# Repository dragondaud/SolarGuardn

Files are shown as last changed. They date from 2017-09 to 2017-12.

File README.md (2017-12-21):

# SolarGuardn
## v0.8.00 PRE-RELEASE 21-Dec-2017
### by David Denney <dragondaud@gmail.com>

Master repository: https://github.com/dragondaud/SolarGuardn

### Features
- ESP8266/Arduino platform
- Over-the-Air (OTA) updates from Arduino IDE
- BME280 to read Temperature, Humidity, Pressure
- Soil moisture reading
- MQTT data logging
- WiFi client
- WiFi web server
- Web server status page
- Telnet server for remote debugging/monitoring
- Pump control with SONOFF/Espurna
- SPIFFS config file

This code is offered "as is" with no warranty, expressed or implied, for any purpose,
and is released to the public domain, while all libraries retain their respective licenses.

See config.h for configurable settings and all includes.

Designed to run on an ESP-12E NodeMCU board with additional hardware,
this sketch will monitor soil conditions, ambient temperature, humidity
and atmospheric pressure, then report changes using MQTT, to AdafruitIO.

A built-in WWW server provides direct access to current data, /reset request will reboot ESP.

Telnet server allows remote monitoring and debugging when serial is not practical.

Press FLASH button on NodeMCU to enter moisture sensor calibration mode, adjust input pot, monitor serial

Press FLASH button twice rapidly to store current running config to SPIFFS

**Board: NodeMCU 1.0, Freq: 80MHz, Flash: 4M (1M SPIFFS), Speed: 115200, Port: serial or OTA IP**

Some code is based on examples from the ESP8266, ArduinoOTA and other libraries.

Sketch requires Arduino ESP8266 board library v2.4.0 from https://github.com/esp8266/Arduino#using-git-version

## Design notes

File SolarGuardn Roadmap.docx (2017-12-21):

# SolarGuardn Roadmap

## Config

WIFI

MQTT

BETWEEN

Fahrenheit

Sensor pins

## Setup

Serial begin

Read config

Set default hostname if null

WiFi begin

MDNS begin

Debug telnet begin

Get location

Config ntp

OTA begin

MQTT connect

GPIO pin modes

Sensor initialize

WWWserver begin

Uptime initialized

Output banner/crash info

## Loop

Restart ESP on null IP

OTA, MQTT, Debug, WWW … handle

Recheck time zone after 2am

Restart loop unless read interval reached

Read sensors

Construct JSON array with sensor data

Publish JSON to MQTT

Blink built-in LED

## Functions

UrlEncode

getIPlocation

getLocation

getTimeZone

setNTP

uptime

mqttConnect

mqttPublish

espStats

ttime

handleWWW

## Includes

ESP8266WiFi.h https://github.com/esp8266/Arduino

ArduinoJson.h https://github.com/bblanchon/ArduinoJson

BME280I2C.h https://github.com/finitespace/BME280

EspSaveCrash.h https://github.com/krzychb/EspSaveCrash

PubSubClient.h https://github.com/knolleary/pubsubclient

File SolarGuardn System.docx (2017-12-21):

# SolarGuardn System

## AirGuard

- ESP w/ Temperature, Humidity, TVOC / eCO2

## SoilGuard

- ESP w/ Temperature, Humidity, Soil Moisture

## TankGuard

- ESP w/ Temperature, Humidity, Ultrasonic Water Level

## LightGuard

- ESP w/ Temperature, Humidity, Full Spectrum Light Sensor

## GuardnPower

- SonOff w/ Power usage, pump/light/solenoid control

## GuardnHub

- Raspberry Pi W Zero, MQTT broker, nosql, automation

## Summary

The SolarGuardn System is made up of a variety of modules that monitor various aspects of the garden environment. Each guard module communicates with the GuardnHub for its configuration and to report data. The GuardnHub runs on a Raspberry Pi with Raspbian Linux. The hub provides a local front-end for module control, configuration, monitoring and event control, as well as uploading the data to the cloud. Without a local hub, all reporting, control and configuration activities rely on having a stable Internet connection.

## Hardware

Each Guard module is based on an ESP module of various types, contains an 18650 2500mAh lipo battery, and is powered either by a Solar cell or a USB charger. The ESP8266 supports WiFi, has one analog input, and several GPIOs available. The ESP32 supports WiFi and Bluetooth, has four analog inputs, and several GPIOs available. The SonOff-POW is an ESP8266 based power relay, with power monitoring built-in, though requires soldering a header inside to program.

SoilGuard uses a capacitive soil moisture sensor, which must be calibrated for the type of growing media and nutrients being used. It is very sensitive to depth of insertion and only works reliably when inserted into undisturbed soil to the correct depth, and not withdrawn or jostled. Improving the usability and reliability of this sensor has been a major focus.

## Parts

(example parts, for prototypes, available more cheaply on ebay)

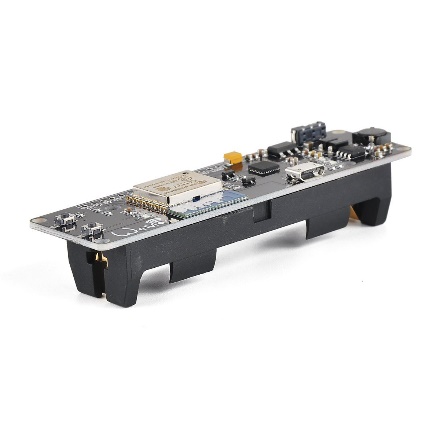
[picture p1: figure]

ESP8266 NodeMCU 1.0 with 18650 battery holder and charging circuit | http://a.co/518tkHj

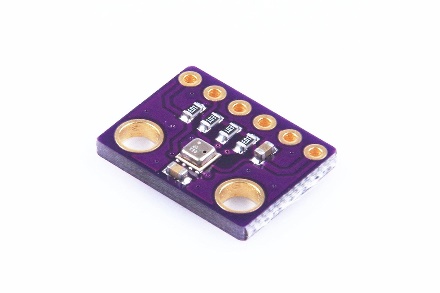
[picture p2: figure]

BME280 weather sensor | http://a.co/6fis93Z

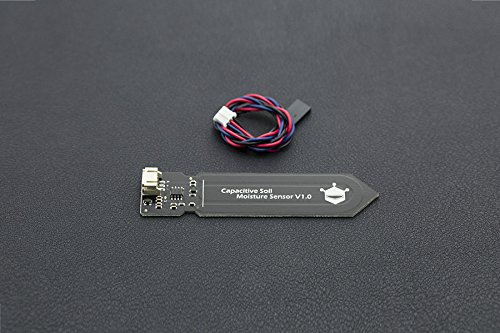
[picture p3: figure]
DFRobot Capacitive Soil Moisture Sensor- Corrosion Resistant

DFRobot Capacitive Soil Moisture sensor | http://a.co/3iVQXh5

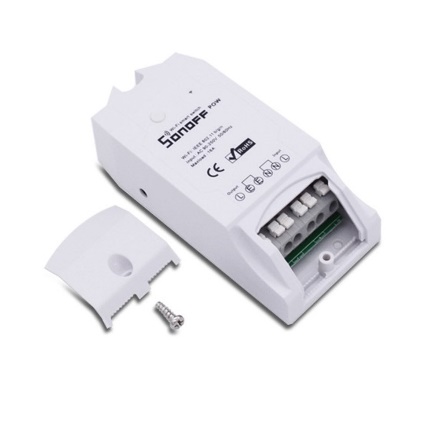
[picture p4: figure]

SonOff Pow | http://a.co/b1oLWcm

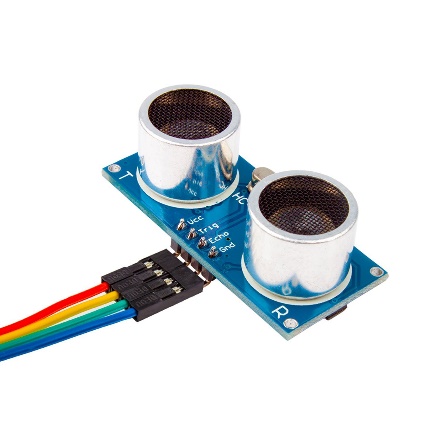
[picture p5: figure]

HC-SR04 Ultrasonic sensor | http://a.co/6q1ENUZ

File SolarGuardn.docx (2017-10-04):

# SolarGuardn v0.7.05 PRE-RELEASE

# Parts

(Only one of each part is needed, but some things are cheaper in quantity if you don’t have them laying around already. The parts specified above are just examples, use what you have laying around or can find locally, as desired)

Description | Source | Price
NodeMCU devkit V1.0 ESP-12E | http://a.co/10eGSEd | $8.69
Solderable Protoboard | http://a.co/g65cxVk (qty 3) | $12.52
Yard light to hack | http://a.co/i6eFgRK | $9.99
DC to DC Voltage Regulator | http://a.co/eJytx5X (qty 5) | $7.99
10K ohm trim pot | http://a.co/iqWQHtd (qty 10) | $7.99
BME280 I2C Weather Sensor | http://a.co/6fis93Z | $12.72
100ohm resistor | http://a.co/1EHDSJW (qty100) | $5.16
NPN transistor | http://a.co/6SemMNQ (qty 100) | $5.90
Electrolytic Capacitor | http://a.co/3eo9hUW | $5.86
Sonoff POW | https://www.itead.cc/sonoff-pow.html | $10.50

I suggest building your circuit on a solderless breadboard first, then transfer to soldered protoboard once you are satisfied with its operation. I highly recommend soldering female header strips to your PCB for the NodeMCU, the BME module and even the transistor, so they’re easily replaced or repurposed.

# Features

- ESP8266/Arduino platform
- Over-the-Air (OTA) updates from Arduino IDE
- BME280 to read Temperature, Humidity, Pressure
- Soil moisture reading
- AdafruitIO/MQTT data logging
- WiFi client, to control other devices
- WiFi web server, for status page and remote reset
- Pump control by custom URL (works with ESPurna (https://bitbucket.org/xoseperez/espurna))
- SPIFFS config file, eventually configured thru web page

# pin definitions

GPIO | Pin label | Description
ADC | A0 | MOIST (analog)
4 | D2 | MPOW
0 | D3 | BUTTON (flash)
14 | D5 | I2C-CLK
12 | D6 | I2C-DAT

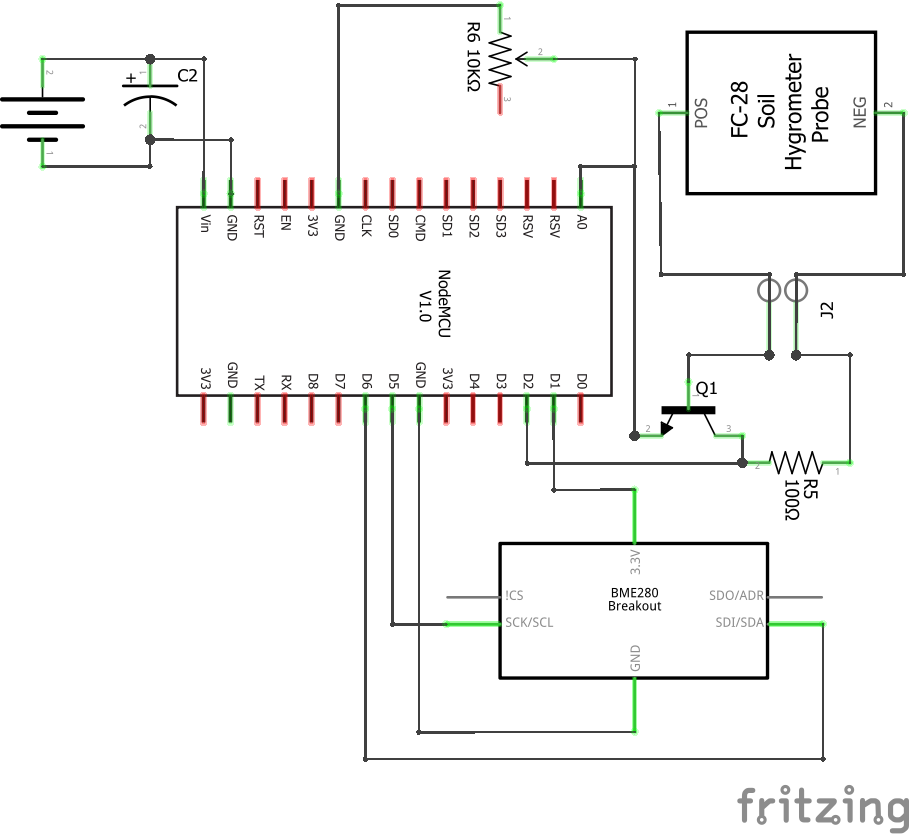
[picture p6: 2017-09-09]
SolarGuardn_schem.png

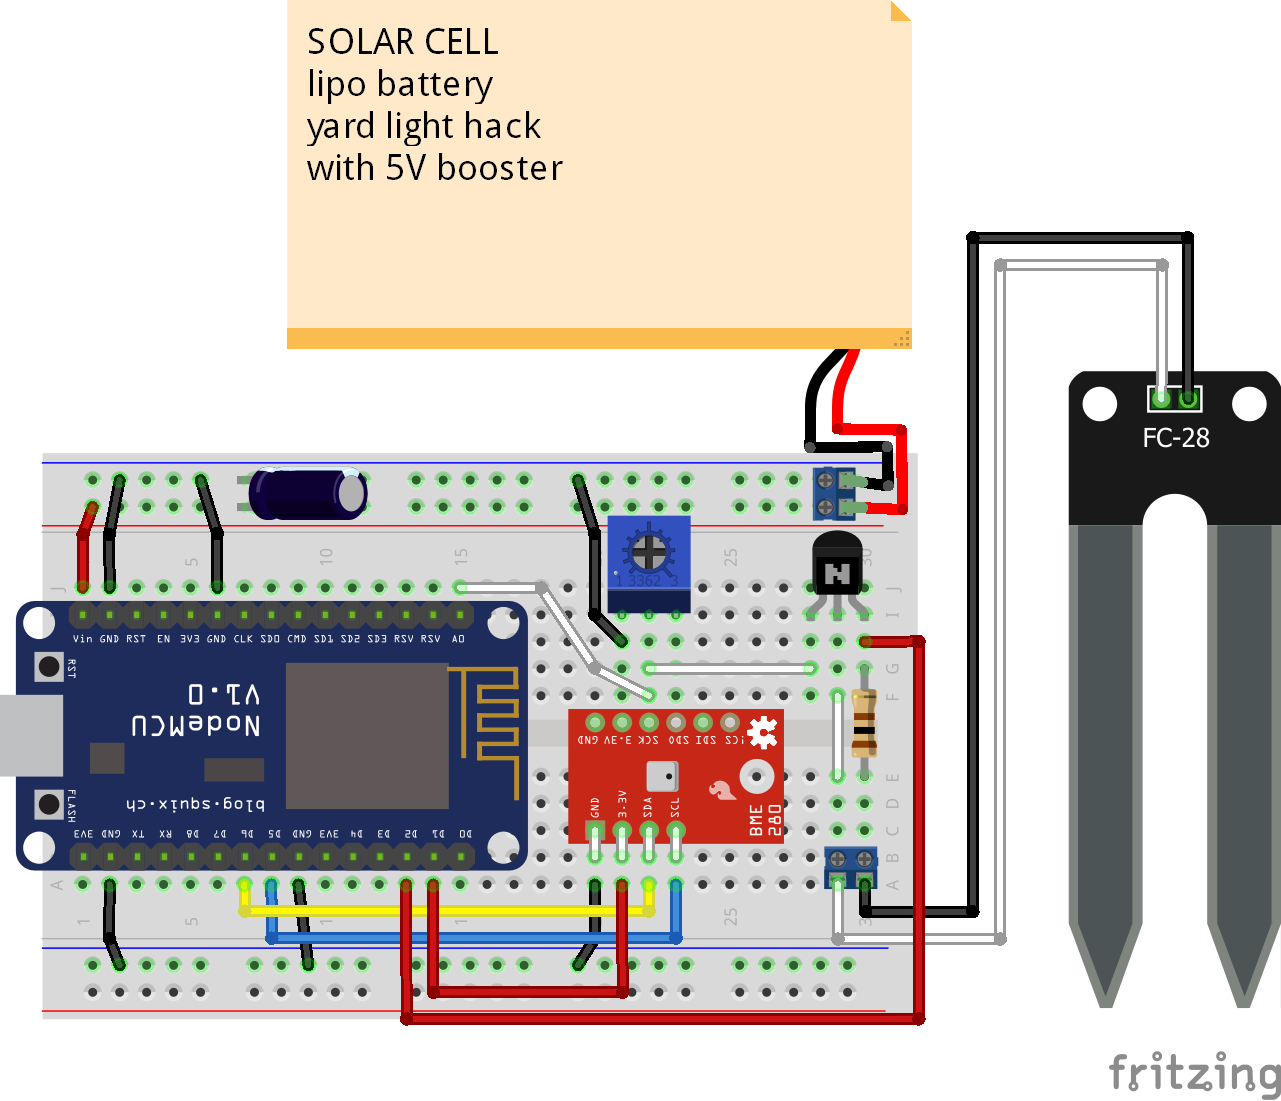
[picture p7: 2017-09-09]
SolarGuardn_bb.png

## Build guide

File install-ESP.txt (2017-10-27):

INSTALL
-------

Install Arduino IDE from http://www.arduino.cc/en/main/software
Install Python 2.7-latest from https://www.python.org/downloads/windows/
Install Github from https://central.github.com/deployments/desktop/desktop/latest/win32

Launch 'Git Bash'

cd ~/Documents/Arduino/
mkdir hardware
cd hardware
mkdir esp8266com
cd esp8266com
git clone https://github.com/esp8266/Arduino.git esp8266
cd esp8266
git fetch origin pull/3362/head:lwip2v2
git merge lwip2v2
cd tools
python get.py

UPDATE
------

Launch 'Git Bash'

cd ~/Documents/Arduino/hardware/esp8266com/esp8266
git fetch origin pull/3362/head:lwip2v2
git merge lwip2v2

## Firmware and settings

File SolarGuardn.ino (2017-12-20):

/*
  SolarGuardn v0.8.00 PRE-RELEASE 26-Oct-2017
  by David Denney

  Monitors garden conditions, cycles irrigation control as needed, reports data using MQTT.

  This code is offered "as is" with no warranty, expressed or implied, for any purpose,
  and is released to the public domain, while all libraries retain their respective licenses.

  Master repository: https://github.com/dragondaud/SolarGuardn

  See config.h for configurable settings and includes.

  Designed to run on an ESP-12E NodeMCU board with additional hardware,
  this sketch will monitor soil conditions, ambient temperature, humidity
  and atmospheric pressure, then report changes using MQTT.

  Built-in WWW server:
    / : display temperature, humidity, pressure, soil moisture
    /reset : reboot module
    /calibrate : start calibration
    /crash : display any saved crash report

  Telnet server allows remote monitoring and debugging when serial is not practical.

  Board: NodeMCU 1.0, Freq: 80MHz, Flash: 4M (1M SPIFFS), Speed: 115200, Port: serial or OTA IP

  Some code is based on examples from the ESP8266, ArduinoOTA and other libraries.

  Sketch requires ESP8266 library v2.4.0-rc1, docs at: https://arduino-esp8266.readthedocs.io/en/2.4.0-rc1/
  You can use the release candidate by adding  this to File->Preferences->Additional Board Manager URLs:
    https://github.com/esp8266/Arduino/releases/download/2.4.0-rc1/package_esp8266com_index.json
*/

#include "config.h"

void setup() {
  Serial.begin(115200);               // Initialize Serial at 115200bps, to match bootloader
  //Serial.setDebugOutput(true);      // uncomment for extra debugging
  while (!Serial);                    // wait for Serial to become available
  delay(100);
  debugOutLN(F("\033[H\033[2JSolarGuardn starting..."));     // CLS and startup banner

  readConfig();                       // mount SPIFFS, config file not implemented yet

  if (HOST == "") {                   // default hostname "SG-000000" where 0000 is last 6 digts of MACaddr
    String t = WiFi.macAddress();
    HOST = "SG-" + t.substring(9, 11) + t.substring(12, 14) + t.substring(15, 17);
  }

  /* WiFi connect */
  WiFi.hostname(HOST);
#ifdef DEBUG
  debugOut("Connecting to ");
  debugOut(WIFI_SSID);
#endif
  WiFi.begin(WIFI_SSID.c_str(), WIFI_PASS.c_str());
  while (WiFi.status() != WL_CONNECTED) {
#ifdef DEBUG
    debugOut(FPSTR(DOT));
#endif
    delay(500);
  }
#ifdef DEBUG
  debugOutLN();
#endif

  /* configTime sntp */
  configTime((TZ * 3600), 0, "pool.ntp.org", "time.nist.gov");
#ifdef DEBUG
  debugOut(F("Synchronize clock with sntp..."));
#endif
  while (!time(nullptr)) {
    delay(1000);                        // wait for ntp time sync
#ifdef DEBUG
    debugOut(FPSTR(DOT));
#endif
  }
#ifdef DEBUG
  debugOutLN();
#endif

#ifdef OTA
  ArduinoOTA.setHostname(HOST.c_str());
  ArduinoOTA.setPort(OTA_PORT);
  if (OTA_PASS) ArduinoOTA.setPassword(OTA_PASS.c_str());
  ArduinoOTA.onStart([]() {
    SPIFFS.end();
    Serial.println(F("\r\nOTA Start"));
  } );
  ArduinoOTA.onEnd([]() {
    Serial.println(F("\r\nOTA End"));
    SPIFFS.begin();
  } );
  ArduinoOTA.onProgress([](unsigned int progress, unsigned int total) {
    Serial.print("OTA Progress: " + String((progress / (total / 100))) + " \r");
  });
  ArduinoOTA.onError([](ota_error_t error) {
    debugOut("Error[" + String(error) + "]: ");
    if (error == OTA_AUTH_ERROR) Serial.println(F("Auth Failed"));
    else if (error == OTA_BEGIN_ERROR) Serial.println(F("Begin Failed"));
    else if (error == OTA_CONNECT_ERROR) Serial.println(F("Connect Failed"));
    else if (error == OTA_RECEIVE_ERROR) Serial.println(F("Receive Failed"));
    else if (error == OTA_END_ERROR) Serial.println(F("End Failed"));
    else Serial.println(F("unknown error"));
    ESP.restart();
  });
  ArduinoOTA.begin();
#ifdef DEBUG
  debugOutLN(F("OTA handler started"));
#endif
#endif // OTA

#ifdef WWW
  wwwServer.begin(); /* start web server */
#ifdef DEBUG
  debugOutLN(F("WWW server started"));
#endif
#endif // WWW

  pinMode(LED_BUILTIN, OUTPUT);   // enable onboard LED output
  pinMode(MGND, OUTPUT);          // moisture sensor ground
  digitalWrite(MGND, LOW);        // moisture sensor ground
  pinMode(MPOW, OUTPUT);          // moisture sensor power
  digitalWrite(MPOW, LOW);        // moisture sensor power
  pinMode(BGND, OUTPUT);          // weather ground output
  digitalWrite(BGND, LOW);        // weather ground low
  pinMode(BPOW, OUTPUT);          // weather power output
  digitalWrite(BPOW, HIGH);       // weather power always on, builtin power saving

  Wire.begin(BDAT, BCLK);         // start I2C for weather sensor
  Wire.setClock(100000);
#ifdef BME
  isBME = bme.begin(BMEid);
  bme.setSampling(Adafruit_BME280::MODE_FORCED,
                  Adafruit_BME280::SAMPLING_X4,  // temperature
                  Adafruit_BME280::SAMPLING_X1,  // pressure
                  Adafruit_BME280::SAMPLING_X4,  // humidity
                  Adafruit_BME280::FILTER_OFF   );
  if (!isBME) debugOutLN(F("Could not find a valid BME280 sensor"));
#else
  hdc.begin(0x40);
  isBME = true;
#endif

#ifdef TELNET
#ifdef DEBUG
  debugOutLN(F("telnet server started"));
#endif
  telnetServer.begin();
  //telnetServer.setNoDelay(true); // drops chars if set true
#endif // TELNET

#ifdef MQTT
  MQTTclient.setServer(MQTT_SERV.c_str(), MQTT_PORT);
  MQTTconnect();
#endif

  controlWater(false);                            // start with water control off

  long tStart = time(nullptr);    // measure delay() accuracy in seconds and reset loop DELAY
  delay(DELAY);
  long tEnd = time(nullptr);
  DELAY = (DELAY / ((tEnd - tStart) * 1000)) * DELAY;

#ifdef DEBUG
  SaveCrash.print();
  espStats();
  debugOut(F("Ready, at "));
  debugOut(ttime() + " (");
  debugOut(DELAY);
  debugOutLN(")");
#endif
} // setup()

#ifdef MQTT
bool publish (String t, String m) {
  String topic = MQTT_TOPIC + "/" + t;
  if (!MQTTclient.connected()) MQTTconnect();
  return MQTTclient.publish(topic.c_str(), m.c_str());
} // publish()

bool MQTTconnect () {
  bool r = MQTTclient.connect(HOST.c_str(), MQTT_USER.c_str(), MQTT_PASS.c_str());
  if (r) {
#ifdef DEBUG
    debugOutLN("Connected to MQTT on " + MQTT_SERV + ":" + String(MQTT_PORT));
    publish("debug", WiFi.localIP().toString() + " " + ESP.getResetReason());
#endif
  } else {
#ifdef DEBUG
    debugOutLN("Could not connect to " + MQTT_SERV);
#endif
  }
  return r;
}
#endif

template <typename T> void debugOut(const T x) {
  Serial.print(x);
#ifdef TELNET
  if (telnetClient && telnetClient.connected()) {
    telnetClient.print(x);
  }
#endif
  yield();
} // debugOut()

void debugOutLN() {
  debugOut(FPSTR(EOL));
}

template <typename T> void debugOutLN(const T x) {
  debugOut(x);
  debugOut(FPSTR(EOL));
} // debugOutLN()

#ifdef TELNET
void handleTelnet(void) {
  if (telnetServer.hasClient()) {
    if (!telnetClient || !telnetClient.connected()) {
      if (telnetClient) {
        telnetClient.stop();
      }
      telnetClient = telnetServer.available();
      telnetClient.flush();
      yield();
#ifdef DEBUG
      debugOut(F("\r\ntelnet connected from "));
      debugOutLN(telnetClient.remoteIP());
#ifdef MQTT
      publish("debug", "telnet " + telnetClient.remoteIP().toString());
#endif
      SaveCrash.print(telnetClient);
      SaveCrash.clear();
      espStats();
#endif
    } else {
      telnetServer.available().stop();
    }
  }
} // handleTelnet()
#endif // TELNET

String upTime() {
  long t = millis() / 1000;
  long s = t % 60;
  long m = (t / 60) % 60;
  long h = (t / (60 * 60)) % 24;
  char ut[10];
  snprintf(ut, sizeof(ut), "%d:%02d:%02d", h, m, s);
  return String(ut);
} // upTime()

void espStats() {
  debugOut(F("SolarGuardn v"));
  debugOutLN(VERSION);
  debugOut(F("Last reset reason: "));
  debugOutLN(ESP.getResetReason());
  debugOut(F("WiFi Hostname: "));
  debugOutLN(WiFi.hostname());
  debugOut(F("WiFi IP addr: "));
  debugOutLN(WiFi.localIP());
  debugOut(F("WiFi MAC addr: "));
  debugOutLN(WiFi.macAddress());
  debugOut(F("WiFi Strength: "));
  debugOutLN(WiFi.RSSI());
  debugOut(F("ESP core version: "));
  debugOutLN(ESP.getCoreVersion());
  debugOut(F("ESP SDK version: "));
  debugOutLN(ESP.getSdkVersion());
  debugOut(F("ESP sketch size: "));
  debugOutLN(ESP.getSketchSize());
  debugOut(F("ESP Flash free: "));
  debugOutLN(ESP.getFreeSketchSpace());
  debugOut(F("ESP Flash Size: "));
  debugOutLN(ESP.getFlashChipRealSize());
  debugOut(F("ESP Flash ChipId: "));
  debugOutLN(ESP.getFlashChipId());
  debugOut(F("ESP free RAM: "));
  debugOutLN(ESP.getFreeHeap());
  debugOut(F("ESP uptime: "));
  debugOutLN(upTime());
  debugOutLN("Moisture range: " + String(WATER) + " > Soaked > " + String(WATER - interval) \
             + " > Wet > " + String(AIR + interval) + " > Dry > " + String(AIR));
} // espStats()

void controlWater(bool cmd) {         // control Sonoff module running ESPurna
#ifdef WATERCON
  HTTPClient http;
  if (cmd) {                          // true == turn on pump
    if ((wTime) && (((millis() - wTime) / 1000) < MINWAIT)) return; // wait before turning pump back on
    http.begin(onURL);
#ifdef DEBUG
    debugOut(F("Water ON"));
#endif
  } else {
    http.begin(offURL);
#ifdef DEBUG
    debugOut(F("Water off"));
#endif
  }
  int httpCode = http.GET();
  if (httpCode > 0) {
#ifdef DEBUG
    debugOutLN("; [HTTP] GET: " + String(httpCode));
#endif
    if (httpCode == HTTP_CODE_OK) {             // only change pump state if successful
      if ((water) || (cmd)) wTime = millis();   // track pump time
      water = cmd;
#ifdef MQTT
      if (cmd) publish("water", "ON");
      else publish("water", "OFF");
#endif
    }
  } else {
#ifdef MQTT
    publish("debug", http.errorToString(httpCode));
#endif
    debugOutLN(" [HTTP] GET failed: " + http.errorToString(httpCode));
  }
  http.end();
#endif
}

void calibrate() {
  debugOutLN(F("==Calibrate Start=="));
  for (int i = 1; i <= 25; i++) {
    yield();
    digitalWrite(MPOW, HIGH);
    delay(i * 10);
    debugOut(String(i * 10) + ":");
    int r = 1023 - analogRead(MOIST);
    digitalWrite(MPOW, LOW);
    debugOut(r);
    delay(i * 12);
    if ((i == 10) || (i == 19) || (i == 25)) debugOut(FPSTR(EOL));
    else debugOut(F(", "));
  }
  debugOutLN(F("==Calibrate End=="));
  startCalibrate = false;
} // calibrate()

int readMoisture(bool VERBOSE) {      // analog input smoothing
  int s = 0;
  for (int i = 0; i < nREAD; i++) {
    int r = 0, x = 0;
    do {
      digitalWrite(MPOW, HIGH);       // power to moisture sensor
      delay(STIME);
      r = 1023 - analogRead(MOIST);   // read analog value from moisture sensor (invert for capacitance sensor)
      digitalWrite(MPOW, LOW);        // turn off moisture sensor
      delay(STIME * 1.2);
      x++;
    } while (((r < AIR) || (r > WATER)) && x < nREAD);  // skip invalid values
    s += r;
    if (VERBOSE) {                    // during calibration, output all values
      debugOut(r);
      debugOut(FPSTR(COMMA));
    }
  }
  int r = round((float)s / (float)nREAD);
  if (VERBOSE) {
    debugOut(F("\b\b = "));
    debugOutLN(r);
  }
  return r;
} // readMoisture()

void readBME() {
  if (!isBME) return;
#ifdef BME
  bme.takeForcedMeasurement();
  temp = bme.readTemperature();                   // read Temp in C
#else
  temp = hdc.readTemperature();                   // read Temp in C
#endif
  if (FAHRENHEIT) temp = temp * 1.8F + 32.0F;     // convert to Fahrenheit
#ifdef BME
  humid = bme.readHumidity();                     // read Humidity
  pressure = round(bme.readPressure() * 0.02953); // read barometric pressure and convert to inHg
#else
  humid = hdc.readHumidity();                     // read Humidity
#endif
}                                                 /*-- add configure option for hPa or inHg --*/

void doMe() {                             // called every 5 seconds to handle background tasks
#ifdef TELNET
  handleTelnet();                         // handle telnet server
  yield();                                // process background tasks
#endif
#ifdef OTA
  ArduinoOTA.handle();                    // handle OTA update requests every 5 seconds
  yield();
#endif
#ifdef MQTT
  if (!MQTTclient.connected()) MQTTconnect();      // reconnect MQTT if needed
  MQTTclient.loop();                               // handle MQTT messages
  yield();
#endif
#ifdef WWW
  WiFiClient client = wwwServer.available(); // serve web requests
  if (client) handleWWW(client);
  yield();
#endif
  if (startCalibrate) calibrate();
  yield();
} // doMe()

void loop() {
  doMe();
  analogWrite(LED_BUILTIN, 1);  // turn on LED to half brightness while collecting sensor input
  readBME();
  soil = readMoisture(false);
#ifdef DEBUG
  debugOut(String(temp, 2));
  if (FAHRENHEIT) debugOut(F("°F, "));
  else debugOut(F("°C, "));
  debugOut(String(humid, 2));
  debugOut(F("% RH, "));
  debugOut(String(pressure / 100.0F, 2));
  debugOut(F(" inHg, "));
  debugOut(soil);
#endif
  if (soil > (AIR + interval)) {
#ifdef DEBUG
    if (soil > (WATER - interval)) debugOutLN(F(" soaked."));
    else debugOutLN(F(" wet."));
#endif
    if (water) {
#ifdef MQTT
      if (soil > (WATER - interval)) {
        publish("debug", "soaked off");
      } else publish("debug", "wet off");
#endif
      controlWater(false);
    }
  } else {
#ifdef DEBUG
    debugOutLN(F(" dry."));
#endif
    if (!water) controlWater(true);
  }
  if (soil != soil_l) {                   // if moisture level has changed then
#ifdef DEBUG
    debugOutLN("save moisture " + String(soil));
#endif
#ifdef MQTT
    publish("moist", String(soil));    // store soil moisture
#endif
    soil_l = soil;
  }
  int tt = round(temp);                   // round off temperature
  if (tt != temp_l && tt < 120) {         // if temp has changed and is valid then
#ifdef DEBUG
    debugOut("save temperature " + String(tt));
    if (FAHRENHEIT) debugOutLN(F("°F"));
    else debugOutLN(F("°C"));
#endif
#ifdef MQTT
    publish("temp", String(tt));       // store rounded temp
#endif
    temp_l = tt;
  }
  int hh = round(humid);                  // round off humidity
  if (hh != humid_l && hh <= 100) {       // if humidity has changed and is valid then
#ifdef DEBUG
    debugOutLN("save humidity " + String(hh) + "%RH");
#endif
#ifdef MQTT
    publish("humid", String(hh));      // store rounded humidity
#endif
    humid_l = hh;
  }
  if (pressure != pressure_l && pressure <= 3000) { // if pressure has changed and is valid then
    char p[10];
    dtostrf(pressure / 100.0F, 5, 2, p);  // convert to string with two decimal places
#ifdef DEBUG
    debugOut(F("save pressure "));
    debugOut(p);
    debugOutLN(F(" inHg"));
#endif
#ifdef MQTT
    publish("pressure", String(p));       // store inHg pressure
#endif
    pressure_l = pressure;
  }
  for (int i = 23; i < 1023; i++) {       // fade LED before sleep loop
    analogWrite(LED_BUILTIN, i);
    delay(1);
  }
  analogWrite(LED_BUILTIN, 0);            // disable analog output on LED
  digitalWrite(LED_BUILTIN, HIGH);        // turn off LED
  for (int x = 0; x < 12; x++) {          // sleep 1 minute between moisture readings to save power
    doMe();                               // while allowing background tasks to run every 5 seconds
    if ((water) && ((readMoisture(false) > AIR + interval) || (((millis() - wTime) / 1000) > MAXWATER))) {
#ifdef MQTT
      publish("debug", "time off");
#endif
      controlWater(false);
    }
#ifdef DEBUG
    debugOut(ttime() + " (" + ESP.getFreeHeap() + " free) \033[K\r");
#endif
    delay(DELAY);                          // delay() allows background tasks to run each invocation
  } // for x
} // loop()

String ttime() {
  time_t now = time(nullptr);
  String t = ctime(&now);
  t.trim();                               // formated time contains \n, bug?
  return t;
} // ttime()

#ifdef WWW
void handleWWW(WiFiClient client) {       // default request serves STATUS page
  if (!client.available()) return;
  char buf[1000];
  char p[10];
  String req = client.readStringUntil('\r');
  String tim = ttime(), upt = upTime();
  client.flush();
#ifdef DEBUG
#ifdef MQTT
  publish("debug", "WWW " + client.remoteIP().toString());
#endif
  debugOut(req);
  debugOut(F(" from "));
  debugOut(client.remoteIP());
#endif
  req.toUpperCase();
  if (req.startsWith("GET /FAV")) {             // send favicon.ico from data directory
    File f = SPIFFS.open("/favicon.ico", "r");
    if (!f) return;
#ifdef DEBUG
    debugOut(F(" send favicon.ico at "));
    debugOutLN(tim);
#endif
    client.println(FPSTR(HTTPOK));
    client.println(F("Content-Type: image/x-icon"));
    client.print(F("Content-Length: "));
    client.println(f.size());
    client.println();
    client.write(f);  // ESP8266 Arduino 2.4.0 library automatically buffers file by just passing handle
    client.flush();
    client.stop();
    f.close();
    return;
  }
  else if (req.startsWith("GET /ROBOT")) {      // robots.txt just in case
#ifdef DEBUG
    debugOut(F(" send robots.txt at "));
    debugOutLN(tim);
#endif
    client.println(FPSTR(HTTPOK));
    client.println(F("Content-Type: text/plain"));
    client.println();
    client.println(F("User-agent: *"));
    client.println(F("Disallow: /"));
    client.flush();
    client.stop();
    return;
  }
  else if (req.startsWith("GET /CAL")) {        // CALIBRATE will start moisture sensor calibration
#ifdef DEBUG
    debugOut(F(" start calibration at "));
    debugOutLN(tim);
#endif
    client.println(F("HTTP/1.1 204 No Content"));
    client.println();
    client.flush();
    client.stop();
    startCalibrate = true;
    return;
  }
  else if (req.startsWith("GET /RESET")) {        // RESET will restart ESP
    client.println(F("HTTP/1.1 204 No Content"));
    client.println();
    client.flush();
    client.stop();
    debugOut(F(" restart ESP at "));
    debugOutLN(tim);
    delay(500);                                   // delay to close connection before reset
    ESP.restart();
  }
  dtostrf(pressure / 100.0F, 5, 2, p);
  snprintf_P(buf, sizeof(buf), WWWSTAT, VERSION, tim.c_str(), upt.c_str(), temp_l, humid_l, p, soil);
  client.println(buf);
  if (req.startsWith("GET /CRASH")) {
    client.println("<pre>");
    SaveCrash.print(client);
    client.println("</pre>");
    SaveCrash.clear();
  }
  client.println("</body></html>");
  client.flush();
  client.stop();
#ifdef DEBUG
  debugOutLN(" send status (" + String(strlen(buf)) + " bytes) at " + tim);
#endif
} // handleWWW()
#endif // WWW

void readConfig() {       // mount flash filesystem to read SPIFFS config file
  if (SPIFFS.begin()) {
#ifdef DEBUG
    debugOutLN(F("SPIFFS mounted."));
#endif
    return;
  }
  else {
    debugOutLN(F("Could not mount file system!"));
    delay(500);
    ESP.restart();
  }
  if (!SPIFFS.exists(CONFIG)) {
    debugOutLN(F("Config file not found"));
  } else {
    File f = SPIFFS.open(CONFIG, "r");
#ifdef DEBUG
    debugOut(F("config.txt: "));
    debugOut(f.size());
    debugOutLN(F(" bytes"));
#endif
    while (f.available()) {
      String t = f.readStringUntil('\n');
      t.trim();
      t.replace("\"", "");
      getConfig(t);
    }
    f.close();
  }
} // readConfig()

void getConfig(String i) {
  int e = i.indexOf("=") + 1;
  if ((e == 1) || (e >= i.length())) return;
  if (i.startsWith(F("host"))) HOST = i.substring(e);
  else if (i.startsWith("TZ")) TZ = i.substring(e).toInt();
  else if (i.startsWith("AIR")) AIR = i.substring(e).toInt();
  else if (i.startsWith("WATER")) WATER = i.substring(e).toInt();
  else if (i.startsWith("FAHRENHEIT")) FAHRENHEIT = i.substring(e).toInt();
  else if (i.startsWith("WIFI_SSID")) WIFI_SSID = i.substring(e);
  else if (i.startsWith("WIFI_PASS")) WIFI_PASS = i.substring(e);
#ifdef OTA
  else if (i.startsWith("OTA_PASS")) OTA_PASS = i.substring(e);
#endif
  else if (i.startsWith("MQTT_SERV")) MQTT_SERV = i.substring(e);
  else if (i.startsWith("MQTT_PORT")) MQTT_PORT = i.substring(e).toInt();
  else if (i.startsWith("MQTT_TOPIC")) MQTT_TOPIC = i.substring(e);
  else if (i.startsWith("MQTT_USER")) MQTT_USER = i.substring(e);
  else if (i.startsWith("MQTT_PASS")) MQTT_PASS = i.substring(e);
  else if (i.startsWith("onURL")) onURL = i.substring(e);
  else if (i.startsWith("offURL")) offURL = i.substring(e);
} // getConfig()

/*
  void writeConfig() {
  File f = SPIFFS.open(CONFIG, "w");
  int c = 0;
  if (!f) {
    debugOutLN(F("Config write failed."));
    return;
  }
  debugOutLN(F("Writing config to flash..."));
  f.printf("host=%s\n", host.c_str());
  f.printf("TZ=%d\n", TZ);
  f.printf("AIR=%d\n", AIR);
  f.printf("WATER=%d\n", WATER);
  f.printf("FAHRENHEIT=%u\n", FAHRENHEIT);
  f.printf("WIFI_SSID=%s\n", WIFI_SSID.c_str());
  f.printf("WIFI_PASS=%s\n", WIFI_PASS.c_str());
  #ifdef OTA
  f.printf("OTA_PASS=%s\n", OTA_PASS.c_str());
  #endif
  f.printf("MQTT_SERV=%s\n", MQTT_SERV.c_str());
  f.printf("MQTT_PORT=%d\n", MQTT_PORT);
  f.printf("MQTT_TOPIC=%s\n", MQTT_TOPIC.c_str());
  f.printf("MQTT_USER=%s\n", MQTT_USER.c_str());
  f.printf("MQTT_PASS=%s\n", MQTT_PASS.c_str());
  f.printf("onURL=%s\n", onURL.c_str());
  f.printf("offURL=%s\n", offURL.c_str());
  f.close();
  debugOutLN(F("Success!"));
  } // writeConfig()
*/

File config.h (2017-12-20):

/* SolarGuardn config.h */

#define VERSION     "0.8.00"
#define EIGHT

#define DEBUG
#define TELNET
#define TELNET_PORT 23
#define MQTT
#define WWW
#define OTA
//#define WATERCON
#define BME
//#define HDC

/** BEGIN USER CONFIG **/
#define USERCONFIG              // include local user config, ignored by git, instead of defaults
#ifdef USERCONFIG
#include "userconfig.h"         // copy the following initializers to userconfig.h and edit as needed
#else
String HOST = "SolarGuardn";    // hostname for DHCP
int TZ = -6;                    // time zone offset, in hours
uint16_t OTA_PORT = 8266;       // default port 8266
String OTA_PASS = "";           // set OTA update password or blank for none
int STIME = 120;                // time delay between sampling analog input in milliseconds
int nREAD = 3;                  // number of samples to average
bool FAHRENHEIT = true;         // display temperature in Fahrenheit
int AIR = 220;                  // sensor value, in air
int WATER = 640;                // sensor value, in water
int MAXWATER = 120;             // max watering time, in seconds
int MINWAIT = 300;              // min time, in seconds, to wait between waterings
String WIFI_SSID = "SSID";
String WIFI_PASS = "PASSWORD";
String MQTT_SERV = "mqtt.local";
uint16_t MQTT_PORT = 1883;
String MQTT_TOPIC = "MQTT";
String MQTT_USER = "";
String MQTT_PASS = "";
String onURL = "http://sonoff.fqdn/api/relay/0?apikey=XXXXX&value=1";
String offURL = "http://sonoff.fqdn/api/relay/0?apikey=XXXXX&value=0";
#endif // USERCONFIG
/** END USER CONFIG **/

#define CONFIG  "/config.txt"     // SPIFFS config file

/* includes */
#include <ESP8266WiFi.h>
#include <ESP8266HTTPClient.h>
#include <time.h>
#include <math.h>
#include <FS.h>
#include <pgmspace.h>               // for flash constants to save ram

#include "EspSaveCrash.h"             // https://github.com/krzychb/EspSaveCrash
#ifdef SAVE_CRASH_SPACE_SIZE
#undef SAVE_CRASH_SPACE_SIZE
#endif
#define SAVE_CRASH_SPACE_SIZE 0x1000  // FLASH space reserved to store crash data

#ifdef OTA
#include <ArduinoOTA.h>             // Over-the-Air updates
#endif

#ifdef BME  /* BME280 config **/
#include <Adafruit_Sensor.h>        // install Adafruit_Sensor and Adafruit_BME280 using Library Manager
#include <Adafruit_BME280.h>
#include <Wire.h>
#define BMEid 0x76                  // BME280 I2C id, default 0x77, alt is 0x76
Adafruit_BME280 bme;                // using I2C comms
#else /* HDC1080 */
#include <Wire.h>
#include "ClosedCube_HDC1080.h"
ClosedCube_HDC1080 hdc;
#endif
bool isBME = false;                   // is sensor present

/* MQTT */
#ifdef MQTT
#include <PubSubClient.h>           // install PubSubClient using Library Manager
WiFiClient wifiClient;
PubSubClient MQTTclient(wifiClient);
#endif

/** Web Server **/
#ifdef WWW
WiFiServer wwwServer(80);
#endif

/** serial or telnet output **/
#ifdef TELNET
WiFiServer  telnetServer(TELNET_PORT);
WiFiClient  telnetClient;
#endif

/** pin defs **/
#define MOIST A0    // moisture sensor analog input
#define MPOW  5     // D1, moisture sensor power
#define MGND  4     // D2, moisture sensor ground

#ifdef BME
#define BCLK  D6    // BME280 I2C SCL (clock)
#define BDAT  D7    // BME280 I2C SDA (data)
#define BGND  D5    // BME280 ground
#define BPOW  D4    // BME280 power
#else
#define BCLK  D4    // HDC1080 I2C SCL (clock)
#define BDAT  D5    // HDC1080 I2C SDA (data)
#define BPOW  D6    // HDC1080 power
#define BGND  D7    // HDC1080 ground
#endif

/** initialize vars **/
int DELAY = 5000;
int soil = 0, soil_l = 1023;
float temp = 0, humid = 0;
int temp_l = 0, humid_l = 0;
int relay = 0, water = 0;
int pressure = 0, pressure_l = 0;
int startCalibrate = 0;
long deBounce = 0, wTime = 0;
volatile int buttonState = HIGH;
int interval = (WATER - AIR) / 3;   // split into dry, wet, soaked

/** FLASH constants, to save on RAM **/
static const PROGMEM char DOT[] = ".";
static const PROGMEM char COMMA[] = ", ";
static const PROGMEM char EOL[] = "\033[K\r\n";

#ifdef WWW
static const PROGMEM char HTTPOK[] = "HTTP/1.1 200 OK";
static const PROGMEM char WWWSTAT[] = "HTTP/1.1 200 OK\r\nContent-Type: text/html\r\n\r\n<!DOCTYPE HTML>\
<html><head>\
  <meta http-equiv='refresh' content='60;URL=/'/>\
  <link rel=\"shortcut icon\" href=\"fav.ico\" type=\"image/x-icon\" />\
  <title>SolarGuardn</title>\
  <style>\
    body { background-color: #cccccc; font-family: Arial, Helvetica, Sans-Serif; Color: #000088; }\
  </style>\
</head>\
<body>\
  <h1>SolarGuardn %s </h1>\
  <p>%s</p>\
  <p>uptime %s</p>\
  <p>Temperature: %u &deg;F</p>\
  <p>Humidity: %u%% RH</p>\
  <p>Abs Pressure: %s inHg</p>\
  <p>Soil Moisture: %u </p>";
#endif

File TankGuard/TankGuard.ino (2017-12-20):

/*
   SolarGuardn - TankGuard v0.8.00 PRE-RELEASE 06-Dec-2017
   by David Denney <dragondaud@gmail.com>
*/

#include "Config.h"

void setup() {
  Serial.begin(115200);
  //Serial.setDebugOutput(true);
  while (!Serial);
  flushIn(Serial);
  delay(100);
  Serial.println();
  Serial.print(F("setup: WiFi connecting to "));
  Serial.print(WIFI_SSID);
  Serial.print(F("..."));
  WiFi.persistent(false);
  WiFi.mode(WIFI_STA);
  if (HOST != "") WiFi.hostname(HOST);
  WiFi.begin(WIFI_SSID, WIFI_PASS);
  while (WiFi.status() != WL_CONNECTED) {
    Serial.print(F("."));
    delay(500);
  }
  Serial.println(F(" OK"));
  MDNS.begin(HOST.c_str());

  if (location == "") {
    location = getIPlocation();
  } else {
    getIPlocation();
    location = getLocation(location, gMapsKey);
  }
  setNTP();
  HOST = WiFi.hostname();

  ArduinoOTA.onStart([]() {
    mqttPublish("debug", "OTA UPDATE");
    Serial.println(F("\nOTA: Start"));
  } );
  ArduinoOTA.onEnd([]() {
    Serial.println(F("\nOTA: End"));
    delay(500);
  } );
  ArduinoOTA.onProgress([](unsigned int progress, unsigned int total) {
    Serial.print("OTA Progress: " + String((progress / (total / 100))) + " \r");
  });
  ArduinoOTA.onError([](ota_error_t error) {
    Serial.print("\nError[" + String(error) + "]: ");
    if (error == OTA_AUTH_ERROR) Serial.println(F("Auth Failed"));
    else if (error == OTA_BEGIN_ERROR) Serial.println(F("Begin Failed"));
    else if (error == OTA_CONNECT_ERROR) Serial.println(F("Connect Failed"));
    else if (error == OTA_RECEIVE_ERROR) Serial.println(F("Receive Failed"));
    else if (error == OTA_END_ERROR) Serial.println(F("End Failed"));
    else Serial.println(F("unknown error"));
    delay(5000);
    ESP.restart();
  });
  ArduinoOTA.begin();

  MQTTclient.setServer(MQTT_SERV, MQTT_PORT);
  mqttConnect();

  pinMode(BUILTIN_LED, OUTPUT);

  pinMode(TRIG, OUTPUT);
  digitalWrite(TRIG, LOW);
  pinMode(ECHO, INPUT);

  pinMode(GND, OUTPUT);
  digitalWrite(GND, LOW);
  pinMode(POW, OUTPUT);
  digitalWrite(POW, HIGH);

  Wire.begin(SDA, SCL);
  delay(100);
  isBME = bme.begin();
  if (!isBME) {
    Serial.println(F("cannot find BME280 sensor"));
    delay(5000);
    ESP.restart();
  }

  delay(1000);
  UPTIME = time(nullptr);

  Serial.print(F("Last reset reason: "));
  Serial.println(ESP.getResetReason());
  Serial.print(F("WiFi Hostname: "));
  Serial.println(HOST);
  Serial.print(F("WiFi IP addr: "));
  Serial.println(WiFi.localIP());
  Serial.print(F("WiFi gw addr: "));
  Serial.println(WiFi.gatewayIP());
  Serial.print(F("WiFi MAC addr: "));
  Serial.println(WiFi.macAddress());
  Serial.print(F("ESP Sketch size: "));
  Serial.println(ESP.getSketchSize());
  Serial.print(F("ESP Flash free: "));
  Serial.println(ESP.getFreeSketchSpace());
  Serial.print(F("ESP Flash Size: "));
  Serial.println(ESP.getFlashChipRealSize());
  SaveCrash.print(Serial);
} // setup

void loop() {
  if (WiFi.localIP() == IPAddress(0,0,0,0)) {
    String t = "Invalid null address";
    mqttPublish("debug", t);
    Serial.println(t);
    delay(5000);
    ESP.restart();
  }
  checkSer();
  ArduinoOTA.handle();
  MQTTclient.loop();
  if (millis() > TIMER) {
    TIMER = millis() + BETWEEN;
  } else {
    delay(5000);
    return;
  }
  analogWrite(BUILTIN_LED, 1);
  float temp, humid, pressure;
  int heap = ESP.getFreeHeap();
  time_t now = time(nullptr);
  if (now > TWOAM) {
    Serial.println();
    setNTP();
  }
  String t = ctime(&now);
  t.trim(); // ctime returns extra whitespace
  String u = upTime(now);
  int range = getDist();
  if (isBME) {
    bme.read(pressure, temp, humid);
    temp = temp * 1.8F + 32.0F;
    pressure = pressure * 0.02953;
    Serial.printf("%s, %d°F, %d%%RH, %d.%d inHg, %d mm, %s uptime, %d heap \r", t.c_str(), \
                  round(temp), round(humid), round(pressure / 100), int(pressure) % 100, range, u.c_str(), heap);
  } else {
    Serial.printf("%s, %d mm, %s uptime, %d heap \r", t.c_str(), range, u.c_str(), heap);
  }
  t = "{\"temp\": " + String(round(temp)) + ", \"humid\": " + String(round(humid)) + \
      ", \"range\": " + String(range) + ", \"timestamp\": " + String(now) + ", \"freeheap\": " + String(heap) + "}";
  mqttPublish("data", t);
  for (int i = 23; i < 1023; i++) {
    analogWrite(BUILTIN_LED, i);
    delay(2);
  }
  analogWrite(BUILTIN_LED, 0);
  digitalWrite(BUILTIN_LED, HIGH);
} // loop

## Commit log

2017-09-09 fresh commit for initial beta release
    [SolarGuardn.fzz, config.txt]
2017-09-10 DEBUG, debounce, bugfix
    Add debounce to handleButton
    Add DEBUG to control output
    Add reset on OTA error
    Add freemem display in loop
    Remove handleSerial, not using
    Supress favicon.ico requests
    Add /RESET to remotely reboot
    [SolarGuardn.ino, config.h]
2017-09-11 favicon
    Add support for favicon.ico to web server code. Switched to 'git' version of arduino esp8266 core because it handles WiFi sending of binary data much better.
2017-09-11 fix favicon handling for IE/Edge
    Was working fine in Chrome, but not IE or Edge. Work around was to use 'fav.ico' in html instead of favicon.ico (the default). Works everywhere now. Also needed type: image/x-icon, and to be converted from png to ico format.
    [SolarGuardn.ino]
2017-09-12 RAM optimization
    Moved most contants to flash to save RAM. Also updated word doc to include parts used to build my prototype, including amazon links.
2017-10-12 moisture reading
    Update moisture read function, add calibrate start to web server, uptime function.
2017-10-17 change moisture sensor
    Minor changes in code and comments, mostly to support capacitive moisture sensor.
    [config.txt]
2017-10-19 crash dump
    Added display and clear of saved crash info at begining of telnet connection. Also disabled spiffs config file until rework.
    [SolarGuardn.ino, config.h]
2017-10-19 allow no BME
    If BME280 weather sensor is not present continue reporting in without weather, instead of restarting.
2017-10-20 max watering time
    Added option for max watering time, reworked watering functions
    [SolarGuardn.ino, config.h]
2017-10-20 fixes
    still need spiffs for web server
    [SolarGuardn.ino, config.h]
2017-10-22 calibration
    new calibration routine shows value at various time values
2017-10-24 ICACHE
    add ICACHE_RAM_ATTR to handleButoon to prevent cache miss exception
    [SolarGuardn.ino, config.h]
2017-10-25 add /CRASH
    Add /CRASH to web server, to display and clear SaveCrash. Also added robots.txt disallow all. Disabled button handler because web interface.
    [SolarGuardn.ino, config.h]
2017-10-27 bounds
    fix out of bounds compare
    [SolarGuardn.ino]
2017-12-20 promote mqtt to master
    [config.txt]
2017-12-20 workaround
    workaround ESP losing its IP address occasionally when using lwip2
    [TankGuard.ino]
